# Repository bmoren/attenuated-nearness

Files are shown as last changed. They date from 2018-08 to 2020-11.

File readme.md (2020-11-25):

# Attenuated nearness
##### (aka. *52800*)
## Nearness with attenuators for each input

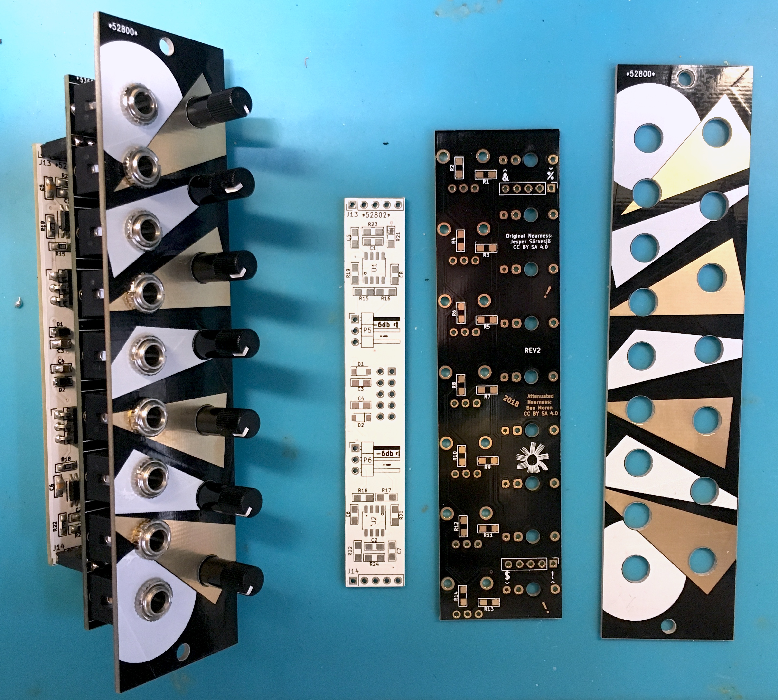
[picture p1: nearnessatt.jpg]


The idea is to have some number of input jacks (seven, here) mixed down to two output jacks, with each input representing a fixed pan position somewhere between the two extremes represented by the outputs. Plug a signal into the topmost input to send it entirely to the top output, the middle one to send it equally to both, etc.

Attenuated nearness builds on this original idea by adding a per input attenuator. This should give more flexibility in using this as a final or only mixing stage in small systems.

More info in this discussion on llllllll.co:
https://llllllll.co/t/prototyping-nearness-a-minimal-panning-mixer-module/8330

Original Nearness Repo: https://github.com/sarnesjo/nearness

## Build guide
1. Start with the surface-mount components. Mind the orientation of the ICs and diodes. (I like to do the whole backpack board first then the jack/pot board)
1. Solder the pin headers to join the 2 boards. (Be mindful of the socket/pin relationship if you are upgrading from a stock nearness.)
1. Place the jacks & pots on the PCB.
1. Screw on the panel, then solder jacks and pots.

## BOM
<a href="nearness_att_bom.csv">Build of Materials</a>

Mouser Project Link:	https://www.mouser.com/ProjectManager/ProjectDetail.aspx?AccessID=e1ea3fb0a7

## License
[CC BY-SA 4.0](http://creativecommons.org/licenses/by-sa/4.0/).    
Build and use at your own risk! I am not responsible for any damage to self or otherwise that arises from using this project!

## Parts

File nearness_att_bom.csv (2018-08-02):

 | Qnty | Value | Footprint | Description | Mouser Part # | Notes
C1, C2, | 2 | 22p | 0805 | Capacitor, ceramic, C0G/NP0, 50V, 1% | 77-VJ0805A220FXACBC
C3, C4, | 2 | 22u | 0805 | Capacitor, ceramic | 81-GRM21BR61E226ME4L | Alternate: C2012JB1E226M125AC
C5, C6, C7, C8, | 4 | 100n | 0805 | Capacitor, ceramic | 581-08053C104J
D1, D2, | 2 | 1N5819HW | SOD 123 | Diode | 621-1N5819HW-F
J2, J3, J4, J5, J6, J7, J8, J1, J9, | 9 | PJ301M12 | Thonkiconn | "Thonkiconn" switching mono phone jack |  | https://modularaddict.com/parts/synth-diy-parts/pj301m12-jacks
J10, | 1 | Conn_02x05_Odd_Even | Header 2x05 Pitch 2.54mm | 02x05 | 855-M20-9990546 | 2X 01x05
J11, J12, | 2 | Conn_01x05 | Header 1x05 Pitch2.54mm | 01x05 | 855-M20-9990546
J13, J14, | 2 | Conn_01x05 | Socket 1x05 Pitch2.54mm | 01x05 | 855-M20-7820542
P5, P6, | 2 | CONN_01X03 | Header Angled 1x03 Pitch2.54mm | 01x03 | 538-22-28-8034
R1, R14, R15, R16, R17, R18, R19, R20, R21, R22, | 10 | 100k | 0805 | Resistor, thin film, 0.1% | 667-ERA-6AEB104V
R2, R13, | 2 | 1M67 | 0805 | Resistor, thick film, 1% | 667-ERJ-6ENF1694V | Original Nearness: 1M69K
R3, R12, | 2 | 103k | 0805 | Resistor, thin film, 0.1% | 667-ERA-6AEB1023V | Original Nearness: 102K
R4, R11, | 2 | 439k | 0805 | Resistor, thin film, 0.1% | 667-ERA-6AEB4423V | Original Nearness: 442k
R5, R10, | 2 | 113k | 0805 | Resistor, thin film, 0.1% | 667-ERA-6AEB1133V
R6, R9, | 2 | 215k | 0805 | Resistor, thin film, 0.1% | 667-ERA-6AEB2153V
R7, R8, | 2 | 141k | 0805 | Resistor, thin film, 0.1% | 667-ERA-6AEB1403V | Original Nearness: 140K
R23, R24, | 2 | 1k | 0805 | Resistor, thin film, 0.1% | 667-ERA-6AEB102V
RV1, RV2, RV3, RV4, RV5, RV6, RV7, | 7 | A10K | tall trimmer pot 9mm | Potentiometer A10K |  | https://modularaddict.com/parts/synth-diy-parts/9mm-tall-trimmer-potentiometers
U1, U2, | 2 | LME49720 | SOIC-8 3.9x4.9mm Pitch1.27mm |  | 926-LME49720MAX/NOPB
Jumper | 2 | Jumper

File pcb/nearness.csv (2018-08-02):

Source: | /Users/bmoren/Desktop/module development/nearness-master/nearness_att/pcb/nearness.sch
Date: | Wednesday, June 27, 2018 at 08:16:27 AM
Tool: | Eeschema (5.0.0-rc2-47-g52fceb3)
Generator: | /private/var/folders/fh/bd0h7kx1015c__2l59y4f1g40000gp/T/AppTranslocation/2CC4E22D-46EE-4DF7-97BE-BB20CBD617AF/d/kicad.app/Contents/SharedSupport/plugins/bom_csv_grouped_by_value_with_fp.py
Component Count: | 59
Ref | Qnty | Value | Cmp name | Footprint | Description | Vendor
C1, C2, | 2 | 22p | C | modular:C_0805_HandSoldering_TopLabel | Unpolarized capacitor
C3, C4, | 2 | 22u | C | modular:C_0805_HandSoldering_TopLabel | Unpolarized capacitor
C5, C6, C7, C8, | 4 | 100n | C | modular:C_0805_HandSoldering_TopLabel | Unpolarized capacitor
D1, D2, | 2 | 1N5819HW | D | Diodes_SMD:D_SOD-123 | Diode
J2, J3, J4, J5, J6, J7, J8, J1, J9, | 9 | PJ301M12 | PJ301M12 | modular:Thonkiconn_small_holes | "Thonkiconn" switching mono phone jack
J10, | 1 | Conn_02x05_Odd_Even | Conn_02x05_Odd_Even | Pin_Headers:Pin_Header_Straight_2x05_Pitch2.54mm | Generic connector, double row, 02x05, odd/even pin numbering scheme (row 1 odd numbers, row 2 even numbers)
J11, J12, | 2 | Conn_01x05 | Conn_01x05 | Pin_Headers:Pin_Header_Straight_1x05_Pitch2.54mm | Generic connector, single row, 01x05
J13, J14, | 2 | Conn_01x05 | Conn_01x05 | Socket_Strips:Socket_Strip_Straight_1x05_Pitch2.54mm | Generic connector, single row, 01x05
P5, P6, | 2 | CONN_01X03 | CONN_01X03-RESCUE-nearness | Pin_Headers:Pin_Header_Angled_1x03_Pitch2.54mm
R1, R14, R15, R19, R21, R17, R20, R22, R16, R18, | 10 | 100k | R | modular:R_0805_HandSoldering_TopLabel | Resistor
R2, R13, | 2 | 1M67 | R | modular:R_0805_HandSoldering_TopLabel | Resistor
R3, R12, | 2 | 103k | R | modular:R_0805_HandSoldering_TopLabel | Resistor
R4, R11, | 2 | 439k | R | modular:R_0805_HandSoldering_TopLabel | Resistor
R5, R10, | 2 | 113k | R | modular:R_0805_HandSoldering_TopLabel | Resistor
R6, R9, | 2 | 215k | R | modular:R_0805_HandSoldering_TopLabel | Resistor
R7, R8, | 2 | 141k | R | modular:R_0805_HandSoldering_TopLabel | Resistor
R23, R24, | 2 | 1k | R | modular:R_0805_HandSoldering_TopLabel | Resistor
RV1, RV2, RV3, RV4, RV5, RV6, RV7, | 7 | POT | POT | modular:tall_trimmer_pot_9mm | Potentiometer
U1, U2, | 2 | LME49720 | LME49720 | Housings_SOIC:SOIC-8_3.9x4.9mm_Pitch1.27mm

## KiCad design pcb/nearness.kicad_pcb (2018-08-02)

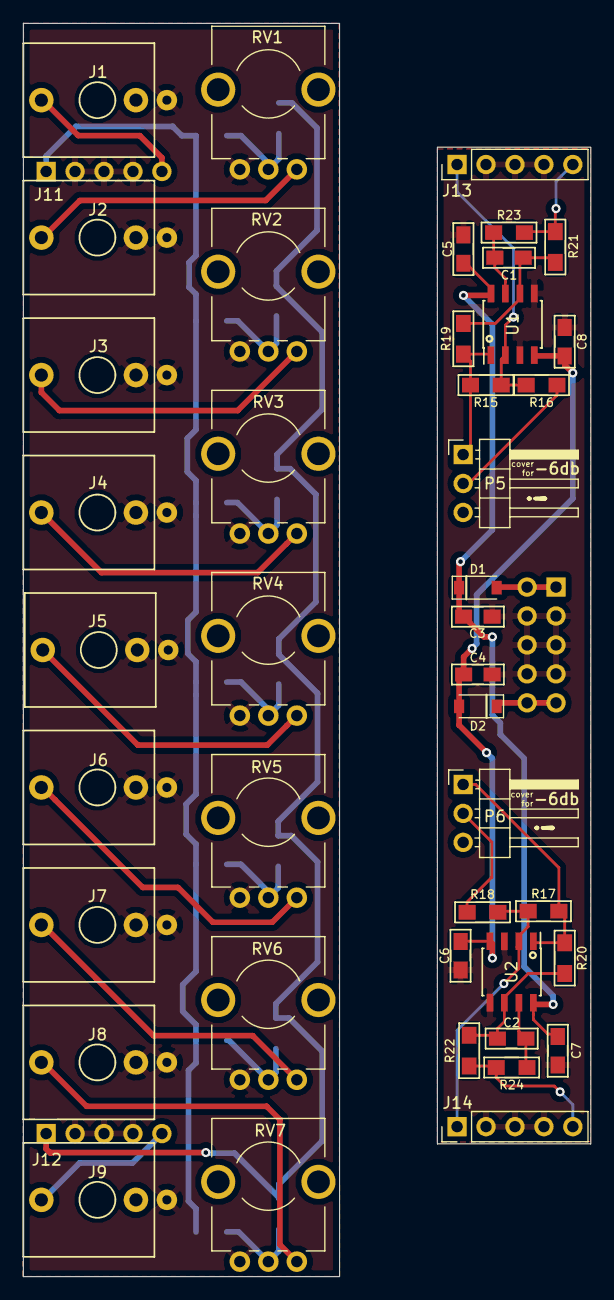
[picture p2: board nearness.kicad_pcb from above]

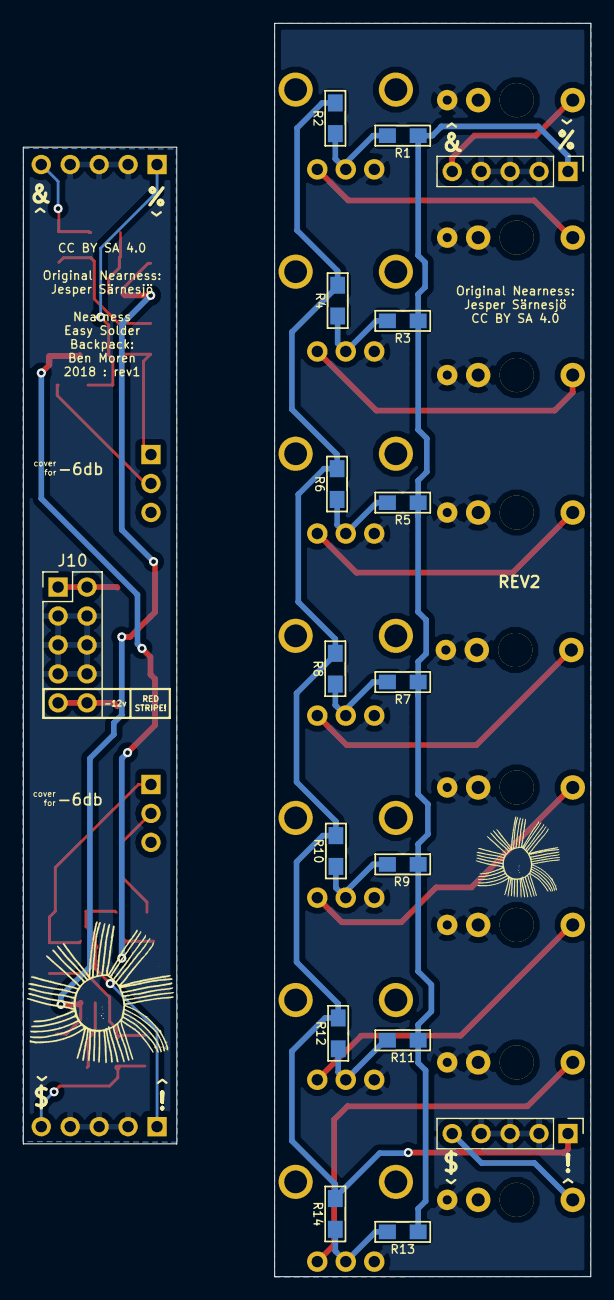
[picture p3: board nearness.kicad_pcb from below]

Board: 2 copper layers, 49.8 x 110.0 mm, 59 parts (17 on the bottom side), 35 nets.

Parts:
C1, C2: 22p; C_0805_HandSoldering_TopLabel
C3, C4: 22u; C_0805_HandSoldering_TopLabel
C5, C6, C7, C8: 100n; C_0805_HandSoldering_TopLabel
D1, D2: 1N5819HW; D_SOD-123
J1, J2, J3, J4, J5, J6, J7, J8, J9: PJ301M12; Thonkiconn_small_holes
J10: Conn_02x05_Odd_Even; Pin_Header_Straight_2x05_Pitch2.54mm
J11, J12: Conn_01x05; Pin_Header_Straight_1x05_Pitch2.54mm
J13, J14: Conn_01x05; Socket_Strip_Straight_1x05_Pitch2.54mm
P5, P6: CONN_01X03; Pin_Header_Angled_1x03_Pitch2.54mm
R1, R14, R15, R16, R17, R18, R19, R20, R21, R22: 100k; R_0805_HandSoldering_TopLabel
R2, R13: 1M67; R_0805_HandSoldering_TopLabel
R3, R12: 103k; R_0805_HandSoldering_TopLabel
R4, R11: 439k; R_0805_HandSoldering_TopLabel
R5, R10: 113k; R_0805_HandSoldering_TopLabel
R6, R9: 215k; R_0805_HandSoldering_TopLabel
R7, R8: 141k; R_0805_HandSoldering_TopLabel
R23, R24: 1k; R_0805_HandSoldering_TopLabel
RV1, RV2, RV3, RV4, RV5, RV6, RV7: POT; tall_trimmer_pot_9mm
U1, U2: LME49720; SOIC-8_3.9x4.9mm_Pitch1.27mm

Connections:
+12V: C3.1, C5.1, C7.1, D1.1, U1.8, U2.8
-12V: C4.2, C6.2, C8.2, D2.2, U1.4, U2.4
GND: C3.2, C4.1, C5.2, C6.1, C7.2, C8.1, J1.1, J2.1, J2.2, J3.1, J3.2, J4.1, J4.2, J5.1, J5.2, J6.1, J6.2, J7.1, J7.2, J8.1, J8.2, J9.1, J10.3, J10.4, J10.5, J10.6, J10.7, J10.8, J11.2, J11.3, J11.4, J12.2, J12.3, J12.4, J13.2, J13.3, J13.4, J14.2, J14.3, J14.4, RV1.1, RV2.1, RV3.1, RV4.1, RV5.1, RV6.1, RV7.1, U1.3, U1.5, U2.3, U2.5
unnamed: C1.1, R19.2, R21.1, U1.6
unnamed: C1.2, R23.1, U1.7
unnamed: C2.1, R20.2, R22.1, U2.6
unnamed: C2.2, R24.1, U2.7
unnamed: D1.2, J10.1, J10.2
unnamed: D2.1, J10.9, J10.10
unnamed: J1.3, J11.5
unnamed: J2.3, RV1.3
unnamed: J3.3, RV2.3
unnamed: J4.3, RV3.3
unnamed: J5.3, RV4.3
unnamed: J6.3, RV5.3
unnamed: J7.3, RV6.3
unnamed: J8.3, RV7.3
unnamed: J11.1, R1.2, R3.2, R5.2, R7.2, R9.2, R11.2, R13.2
unnamed: J12.1, R2.2, R4.2, R6.2, R8.2, R10.2, R12.2, R14.2
unnamed: J9.3, J12.5
unnamed: J13.1, R15.1, R16.1, U1.2
unnamed: J13.5, R21.2, R23.2
unnamed: J14.1, R17.1, R18.1, U2.2
unnamed: J14.5, R22.2, R24.2
unnamed: P5.1, R15.2, R19.1, U1.1
unnamed: P5.2, R16.2
unnamed: P6.1, R17.2, R20.1, U2.1
unnamed: P6.2, R18.2
unnamed: R1.1, R2.1, RV1.2
unnamed: R3.1, R4.1, RV2.2
unnamed: R5.1, R6.1, RV3.2
unnamed: R7.1, R8.1, RV4.2
unnamed: R9.1, R10.1, RV5.2
unnamed: R11.1, R12.1, RV6.2
unnamed: R13.1, R14.1, RV7.2

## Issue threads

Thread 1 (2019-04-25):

Non-standard mounting hole location?

hedefalk, 2019-04-25:
I noticed the placement of the holes in the middle, but didn't think much about it until I finished the build and was going to mount it in a case with threaded inserts… Was it intentional to only target sliding nuts or am I missing something? Is this a common thing? I only have cases with threaded inserts…

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

bmoren, 2019-04-25:
It's not so much that it's intentionally targeted for sliding nuts. More that I'm just one person modifying the original nearness design for my own needs. It's been a minute since I made this panel, but iirc, the hole should be on a standard 3 HP offset from the left, do you have a 3HP module that can go adjacent?

I suppose I'm just here to say, it's not some malicious anti-threaded strip gesture. I'm not a manufacturer; this is an open source project and I'm one person making things I want for my own rack.

It shouldn't be too difficult to design a panel that works better for threaded strips (has a 1 or 2HP offset). If you do, please submit it to this repository with a pull request, and I'd be happy to make it the new standard!

bmoren, 2019-04-25:
although, I will admit while looking at the A100 construction details, to directly answer your question, yes, the holes are in a non-standard position:

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

http://www.doepfer.de/a100_man/a100m_e.htm

bmoren, 2019-04-25:
PCB material is very easy to drill, put some masking tape on either side to prevent blowouts, grab a drill bit and you should be able to make new holes no problem.

hedefalk, 2019-04-25:
>yes, the holes are in a non-standard position; they are at 15.24mm:

Yeah, holes need to be 7.5+5.08X from the left

> this is an open source project and I'm one person making things I want for my own rack.

Totally understand and NP! Just wanted to report back to make the world a better place :)

bmoren, 2019-04-25:
I think I will try to make a new panel to account for the a100 hole location soon. When I made this one I had only just made it on a HP increment and didn't notice that 7.5mm offset, but this makes sense as it's ~1.5hp on either side. So the hole is 'centered'

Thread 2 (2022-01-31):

Loud sound can cover other sounds?

sdwhsrw, 2022-01-31:
I just build mine attenuated nearness, and I find when one of the input is too loud or very dynamic, the sound from other inputs will be covered or interrupted by it, until it becomes quite.

Just like a sidechain compressor.

Is it because the nearness is just a easy mixer, or something wrong with my diy nearness?

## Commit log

2018-08-02 add bom
    [nearness_att_bom.csv.csv]
2018-08-02 fix bom
    [nearness_att_bom.csv]
